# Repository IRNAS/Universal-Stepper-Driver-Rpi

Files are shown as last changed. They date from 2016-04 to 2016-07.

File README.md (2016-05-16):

# Universal Stepper Driver RPi

Here you can find documentation for Universal stepper driver in shape of Raspberry Pi Hat. It supports all signals for Bipolar stepper motors thrue RPi header and have Unipolar stepper connectors and drivers. This driver is GRBL comatibile.

board_diagram
#### Features
- switching power supplay
- USB connector
- current mesurment
- unipolar stepper motor drivers on board
- RPi connector
- encoder connectors
- endswitch connector
- universal serial connector
- 2x LED
- 1x push button

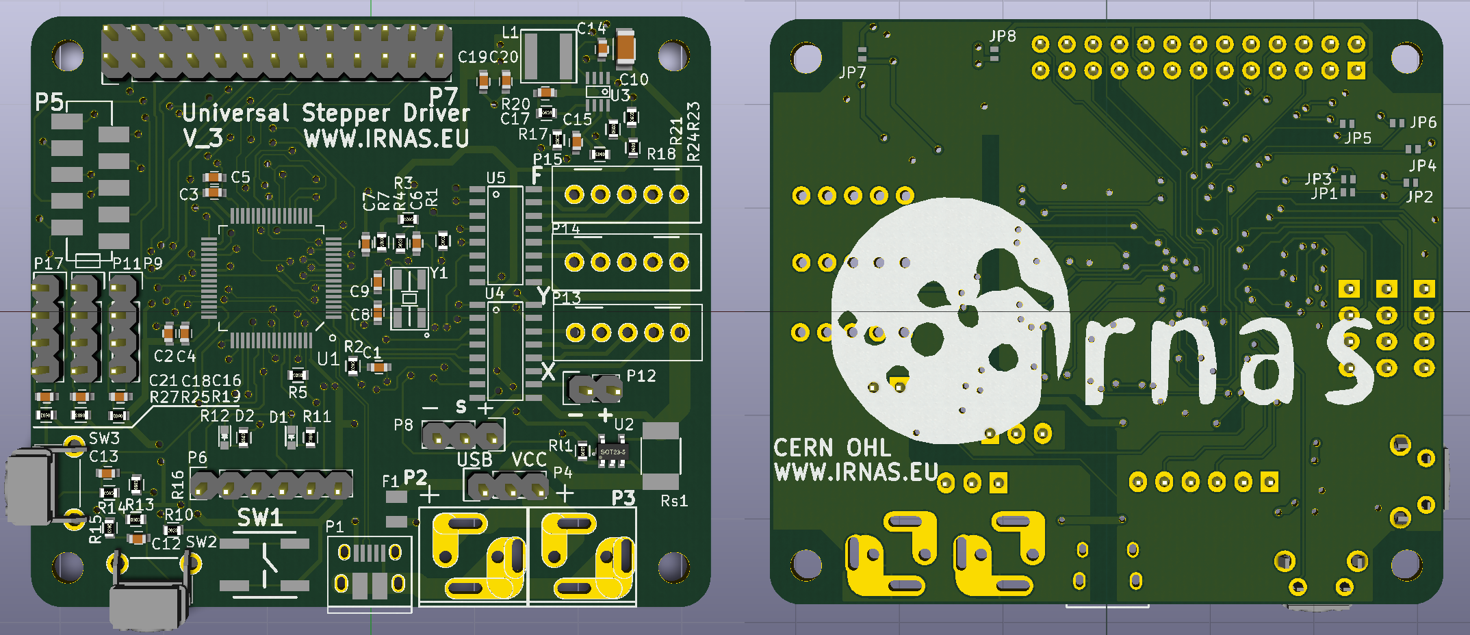
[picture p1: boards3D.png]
board_3D


#### Hardware
Schematics and PCB are designed with open source EDA tool KiCad, all nesesery design files are in this repository.

#### Software
Firmware and all the nessery documentation for Universal Stepper Driver RPi can be found in this [repository](https://github.com/IRNAS/grbl_stm32).

This is currently in testing phase.

#### Known Isues
- Universal serial connector footprint is not good, need to be changed

---

#### License

All our projects are as usefully open-source as possible.

Hardware including documentation is licensed under [CERN OHL v.1.2. license](http://www.ohwr.org/licenses/cern-ohl/v1.2)

Firmware and software originating from the project is licensed under [GNU GENERAL PUBLIC LICENSE v3](http://www.gnu.org/licenses/gpl-3.0.en.html).

Open data generated by our projects is licensed under [CC0](https://creativecommons.org/publicdomain/zero/1.0/legalcode).

All our websites and additional documentation are licensed under [Creative Commons Attribution-ShareAlike 4 .0 Unported License] (https://creativecommons.org/licenses/by-sa/4.0/legalcode).

What this means is that you can use hardware, firmware, software and documentation without paying a royalty and knowing that you'll be able to use your version forever. You are also free to make changes but if you share these changes then you have to do so on the same conditions that you enjoy.

Koruza, GoodEnoughCNC and IRNAS are all names and marks of Institut IRNAS Rače. 
You may use these names and terms only to attribute the appropriate entity as required by the Open Licences referred to above. You may not use them in any other way and in particular you may not use them to imply endorsement or authorization of any hardware that you design, make or sell.

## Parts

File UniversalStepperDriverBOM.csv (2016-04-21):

Id | Designator | Package | Quantity | Designation | Supplier and ref
1 | REF**,REF**,REF**,REF** | MountingHole_3mm | 4 | MountingHole_3mm
2 | C1,C2,C3,C4,C5,C6,C7,C12,C13,C14,C15,C16,C17,C18,C21 | C_0603 | 15 | 100nF
3 | C8,C9 | C_0603 | 2 | 20pF
4 | C10 | C_0603 | 1 | 10uF
5 | C19,C20 | C_0603 | 2 | 22pF
6 | D1 | LED_0603 | 1 | LED_RED
7 | D2 | LED_0603 | 1 | LED_GREEN
8 | F1 | Fuse_SMD1206_Reflow | 1 | F_Small
9 | JP1,JP2,JP3,JP4,JP5,JP6,JP7,JP8 | bridgeJumper | 8 | Jumper_NC_Small
10 | L1 | Inductor SMD XAL50 | 1 | 10uH
11 | P1 | USB_Micro-B_10103594-0001LF | 1 | USB_OTG
12 | P2,P3 | terminal_block_dc_jack_5mm_wide | 2 | CONN_01X02
13 | P4,P8 | Pin_Header_Straight_1x03 | 2 | CONN_01X03
14 | P5 | micromatch | 1 | Universal_Serial_Connector
15 | P6 | Pin_Header_Straight_1x06 | 1 | CONN_01X06
16 | P7 | Pin_Header_Straight_2x13 | 1 | RPI_header
17 | P9,P11,P17 | Pin_Header_Straight_1x04 | 3 | CONN_01X04
18 | P12 | Pin_Header_Straight_1x02 | 1 | CONN_01X02
19 | P13,P14,P15 | 28BYJ-48 | 3 | CONN_28BYJ-48
20 | R1,R2,R3,R4 | R_0603 | 4 | 0R
21 | R5,R10,R19,R25,R27 | R_0603 | 5 | 10k
22 | R7 | R_0603 | 1 | 100k
23 | R11,R12 | R_0603 | 2 | 1k
24 | R13,R14 | R_0603 | 2 | 4k7
25 | R15,R16 | R_0603 | 2 | 100R
26 | R17 | R_0603 | 1 | 1M
27 | R18 | R_0603 | 1 | 100K
28 | R20 | R_0603 | 1 | 20R
29 | R21 | R_0603 | 1 | 51k
30 | R23 | R_0603 | 1 | 13k
31 | R24 | R_0603 | 1 | 41k2
32 | Rl1 | R_0603 | 1 | 16k5
33 | Rs1 | R_1812 | 1 | 0.1R
34 | U1 | QFP_64 | 1 | STM32F411RE
35 | U2 | SOT-23-5 | 1 | INA169
36 | U3 | TSOT32-8 | 1 | MPQ4420
37 | U4,U5 | R-PDSO-G16 | 2 | ULN2003V
38 | Y1 | SPK5032 | 1 | CRYSTAL_SMD_16MHz
39 | SW2,SW3 | SW_Tactile_SPST_Angled | 2 | SW_PUSH
40 | SW1 | KSEK43J_LFS_TACTILE_SWITCH | 1 | SW_PUSH
41 | G*** | LOGO_irnas1 | 1 | LOGO

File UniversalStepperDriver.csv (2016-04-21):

Reference, | Value, | Footprint, | Datasheet
P1,USB_OTG,Connect:USB_Micro-B_10103594-0001LF,http://www.farnell.com/datasheets/1469075.pdf
F1,F_Small,Fuse_Holders_and_Fuses:Fuse_SMD1206_Reflow,http://www.tme.eu/en/Document/92540abe48b0088862e73e73da7a3377/typ_USI_1206.pdf
P2,CONN_01X02,.pretty:terminal_block_dc_jack_5mm_wide,
P3,CONN_01X02,.pretty:terminal_block_dc_jack_5mm_wide,
P4,CONN_01X03,Pin_Headers:Pin_Header_Straight_1x03,
U2,INA169,TO_SOT_Packages_SMD:SOT-23-5,http://www.ti.com/lit/ds/symlink/ina169.pdf
Rl1,16k5,Resistors_SMD:R_0603,
Rs1,0.1R,Resistors_SMD:R_1812,
U3,MPQ4420,.pretty:TSOT32-8,
C10,10uF,Capacitors_SMD:C_0603,
C14,100nF,Capacitors_SMD:C_0603,
R17,1M,Resistors_SMD:R_0603,
R18,100K,Resistors_SMD:R_0603,
C15,100nF,Capacitors_SMD:C_0603,
R20,20R,Resistors_SMD:R_0603,
C17,100nF,Capacitors_SMD:C_0603,
L1,10uH,.pretty:Inductor | SMD | XAL50,
C19,22pF,Capacitors_SMD:C_0603,
C20,22pF,Capacitors_SMD:C_0603,
R21,51k,Resistors_SMD:R_0603,
R24,41k2,Resistors_SMD:R_0603,
R23,13k,Resistors_SMD:R_0603,
P13,CONN_28BYJ-48,.pretty:28BYJ-48,
P14,CONN_28BYJ-48,.pretty:28BYJ-48,
P15,CONN_28BYJ-48,.pretty:28BYJ-48,
P9,CONN_01X04,Pin_Headers:Pin_Header_Straight_1x04,
P11,CONN_01X04,Pin_Headers:Pin_Header_Straight_1x04,
P17,CONN_01X04,Pin_Headers:Pin_Header_Straight_1x04,
R19,10k,Resistors_SMD:R_0603,
R25,10k,Resistors_SMD:R_0603,
R27,10k,Resistors_SMD:R_0603,
C16,100nF,Capacitors_SMD:C_0603,
C18,100nF,Capacitors_SMD:C_0603,
C21,100nF,Capacitors_SMD:C_0603,
SW2,SW_PUSH,Buttons_Switches_ThroughHole:SW_Tactile_SPST_Angled,www.ck-http://www.farnell.com/datasheets/921681.pdf
SW3,SW_PUSH,Buttons_Switches_ThroughHole:SW_Tactile_SPST_Angled,http://www.farnell.com/datasheets/921681.pdf
R15,100R,Resistors_SMD:R_0603,
R16,100R,Resistors_SMD:R_0603,
C12,100nF,Capacitors_SMD:C_0603,
C13,100nF,Capacitors_SMD:C_0603,
R14,4k7,Resistors_SMD:R_0603,
R13,4k7,Resistors_SMD:R_0603,
P5,Universal_Serial_Connector,.pretty:micromatch,
JP1,Jumper_NC_Small,.pretty:bridgeJumper,
C1,100nF,Capacitors_SMD:C_0603,
C2,100nF,Capacitors_SMD:C_0603,
C3,100nF,Capacitors_SMD:C_0603,
C4,100nF,Capacitors_SMD:C_0603,
C5,100nF,Capacitors_SMD:C_0603,
R3,0R,Resistors_SMD:R_0603,
R4,0R,Resistors_SMD:R_0603,
C6,100nF,Capacitors_SMD:C_0603,
U1,STM32F411RE,.pretty:QFP_64,http://www2.st.com/content/ccc/resource/technical/document/datasheet/b3/a5/46/3b/b4/e5/4c/85/DM00115249.pdf/files/DM00115249.pdf/jcr:content/translations/en.D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
R2,0R,Resistors_SMD:R_0603,
R1,0R,Resistors_SMD:R_0603,
R5,10k,Resistors_SMD:R_0603,
R7,100k,Resistors_SMD:R_0603,
C7,100nF,Capacitors_SMD:C_0603,
R12,1k,Resistors_SMD:R_0603,
D2,LED_GREEN,LEDs:LED_0603,
D1,LED_RED,LEDs:LED_0603,
P6,CONN_01X06,Pin_Headers:Pin_Header_Straight_1x06,
C8,20pF,Capacitors_SMD:C_0603,
C9,20pF,Capacitors_SMD:C_0603,
Y1,CRYSTAL_SMD_16MHz,.pretty:SPK5032,https://www.sparkfun.com/datasheets/Components/SPK-5032-16MHZ.pdf
P12,CONN_01X02,Pin_Headers:Pin_Header_Straight_1x02,
P8,CONN_01X03,Pin_Headers:Pin_Header_Straight_1x03,
R10,10k,Resistors_SMD:R_0603,
R11,1k,Resistors_SMD:R_0603,
SW1,SW_PUSH,KSEK43J_LFS_TACTILE_SWITCH:KSEK43J_LFS_TACTILE_SWITCH,http://www.farnell.com/datasheets/1839884.pdf
U4,ULN2003V,.pretty:R-PDSO-G16,
U5,ULN2003V,.pretty:R-PDSO-G16,
JP2,Jumper_NC_Small,.pretty:bridgeJumper,
JP3,Jumper_NC_Small,.pretty:bridgeJumper,
JP4,Jumper_NC_Small,.pretty:bridgeJumper,
JP5,Jumper_NC_Small,.pretty:bridgeJumper,
JP6,Jumper_NC_Small,.pretty:bridgeJumper,
P7,RPI_header,Pin_Headers:Pin_Header_Straight_2x13,http://pi4j.com/images/p1header-large.png
JP7,Jumper_NC_Small,.pretty:bridgeJumper,
JP8,Jumper_NC_Small,.pretty:bridgeJumper,

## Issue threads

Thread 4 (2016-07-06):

VDDA pin (pin #13) must allways be connected to +3V3.

MatejGomboc, 2016-07-06:
VDDA pin (pin #13) must allways be connected to +3V3, otherwise MCU cannot be programmed.

VojislavM, 2016-07-18:
R3 and R1 resistors (0 Ohm) must be soldered.

Closed 2016-07-18.

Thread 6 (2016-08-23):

Pin order on SWD debug interface is reversed.

MatejGomboc, 2016-08-23:
Pin order on SWD debug interface is reversed. It should be:

1. - 3V3
2. - TCK
3. - GND
4. - TMS
5. - NRST
6. - SWO

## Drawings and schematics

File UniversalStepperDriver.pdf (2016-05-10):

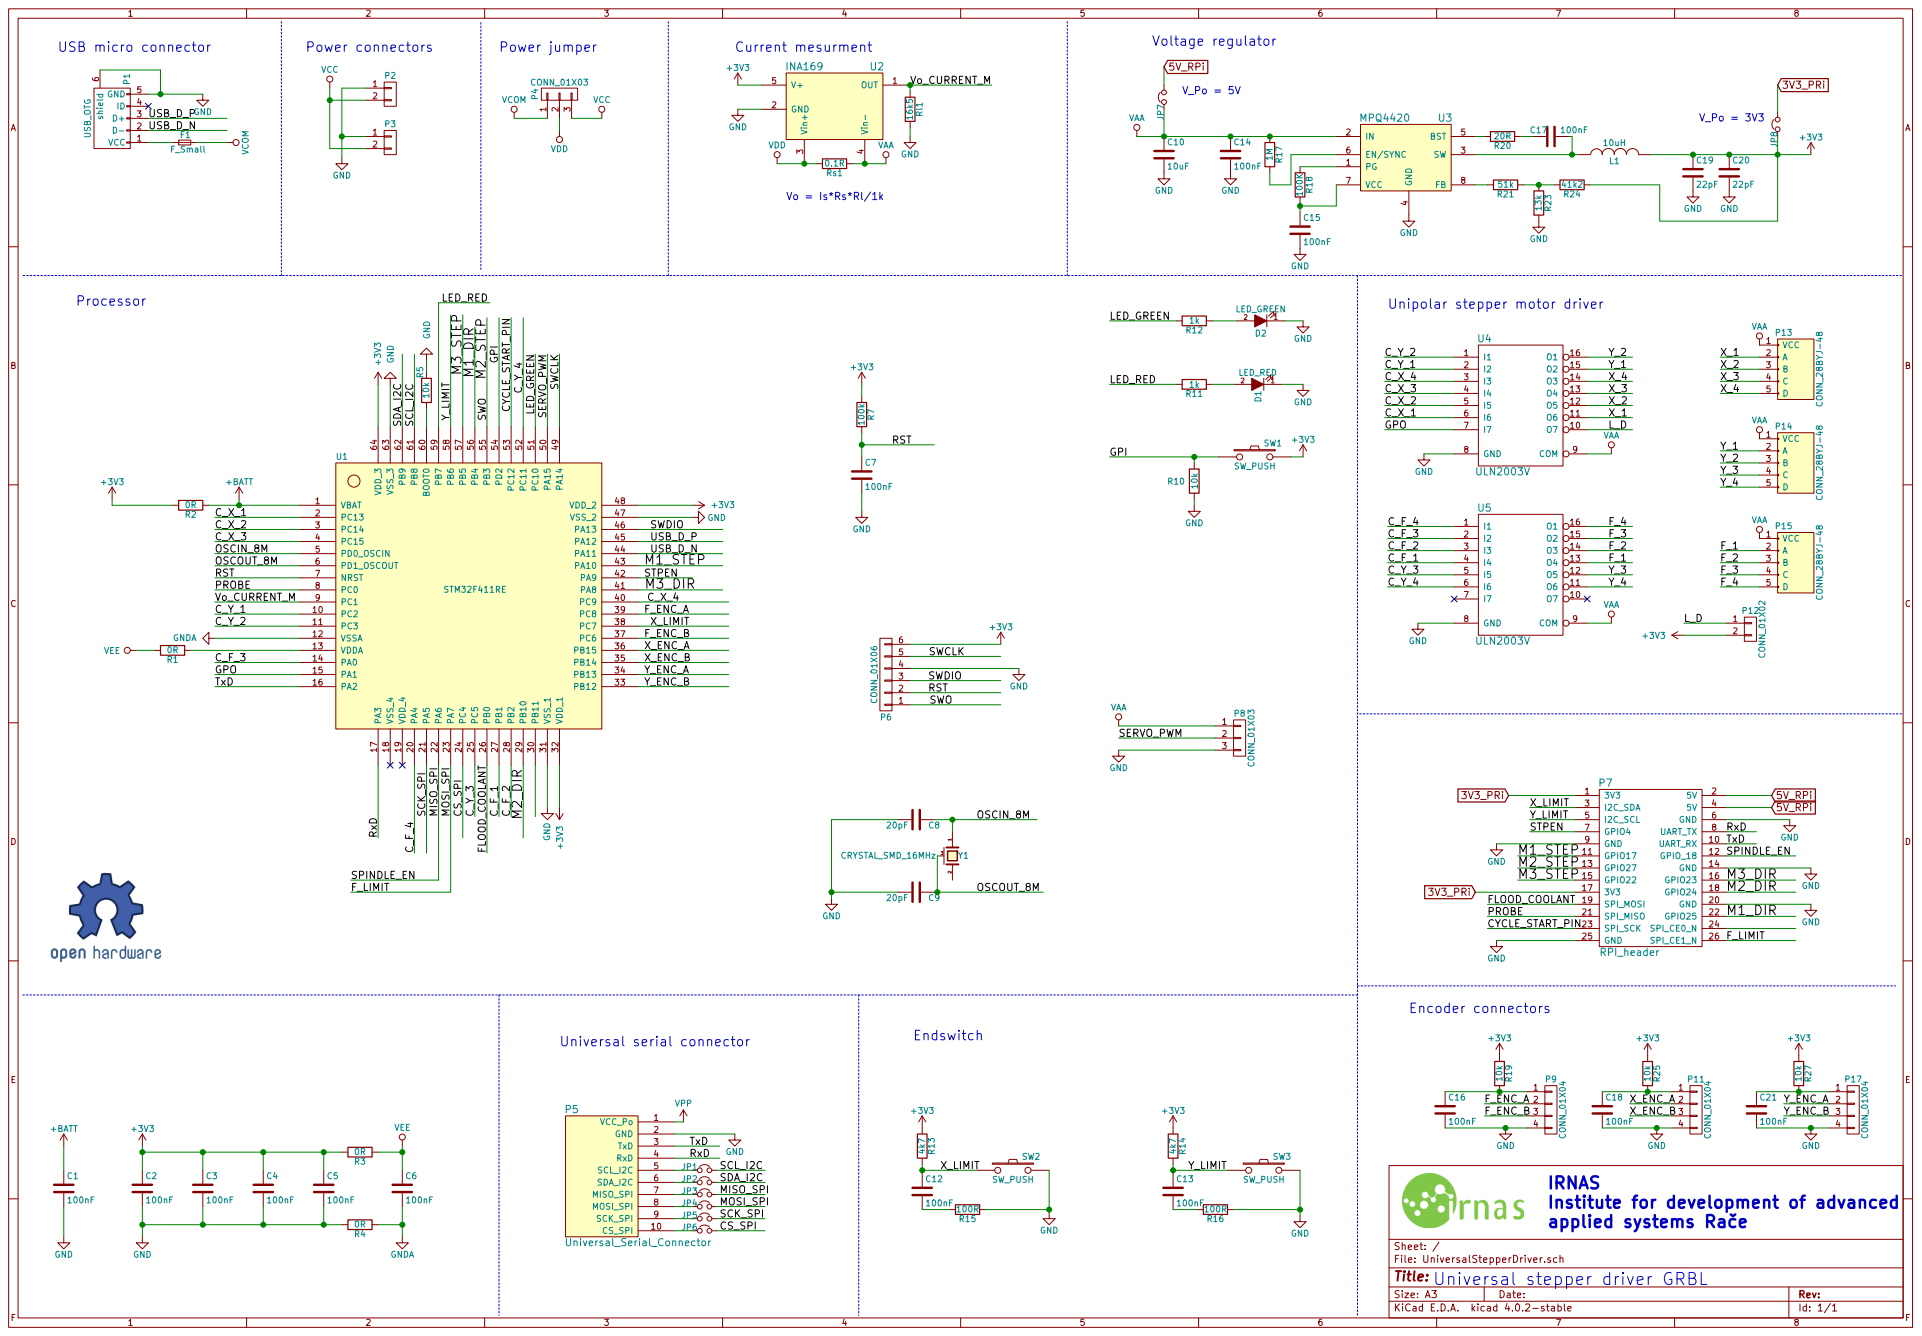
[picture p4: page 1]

4 BST 5 EN/SYNC 6 VCC 7 FB 8 MPQ4420 U3 C10

Unipolar stepper motor driver

F_ENC_A
X_LIMIT

GND Universal serial connector

Institute for development of advanced
applied systems Rae

File: UniversalStepperDriver.sch Sheet: /
Universal stepper driver GRBL

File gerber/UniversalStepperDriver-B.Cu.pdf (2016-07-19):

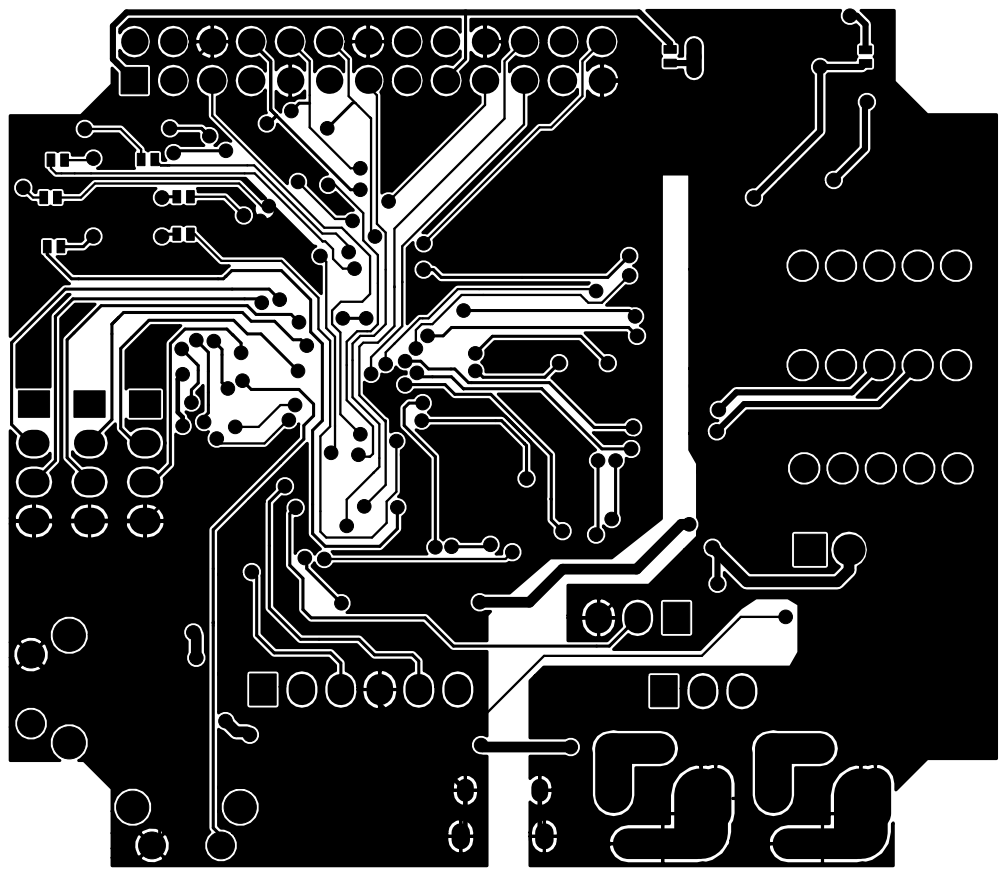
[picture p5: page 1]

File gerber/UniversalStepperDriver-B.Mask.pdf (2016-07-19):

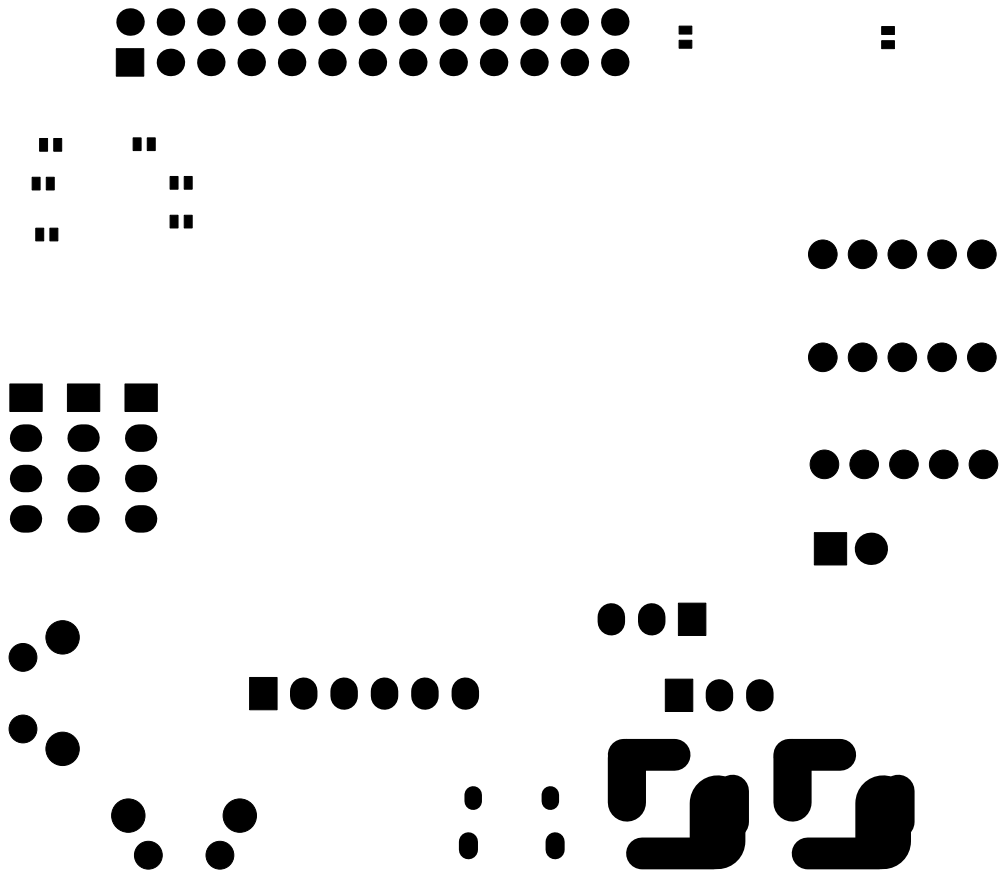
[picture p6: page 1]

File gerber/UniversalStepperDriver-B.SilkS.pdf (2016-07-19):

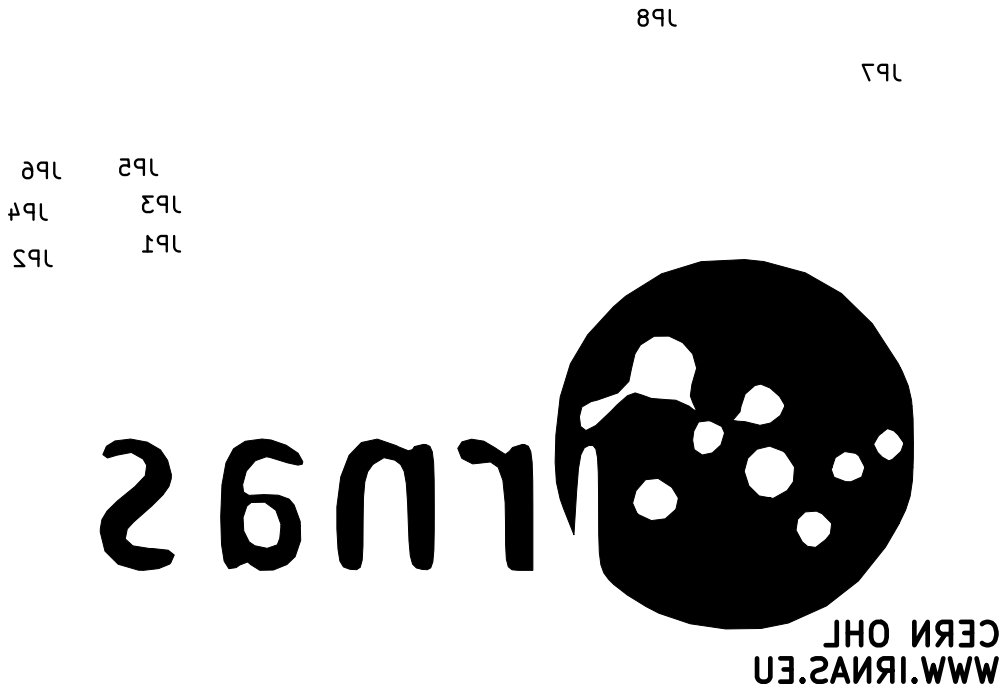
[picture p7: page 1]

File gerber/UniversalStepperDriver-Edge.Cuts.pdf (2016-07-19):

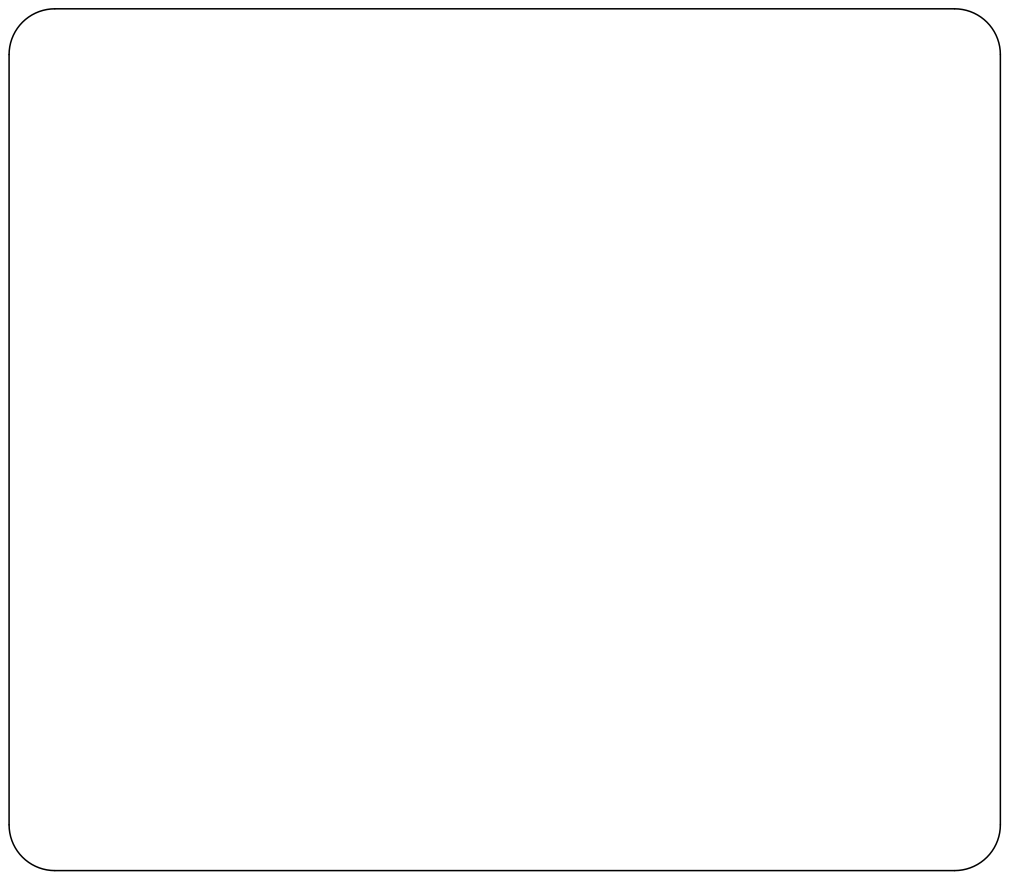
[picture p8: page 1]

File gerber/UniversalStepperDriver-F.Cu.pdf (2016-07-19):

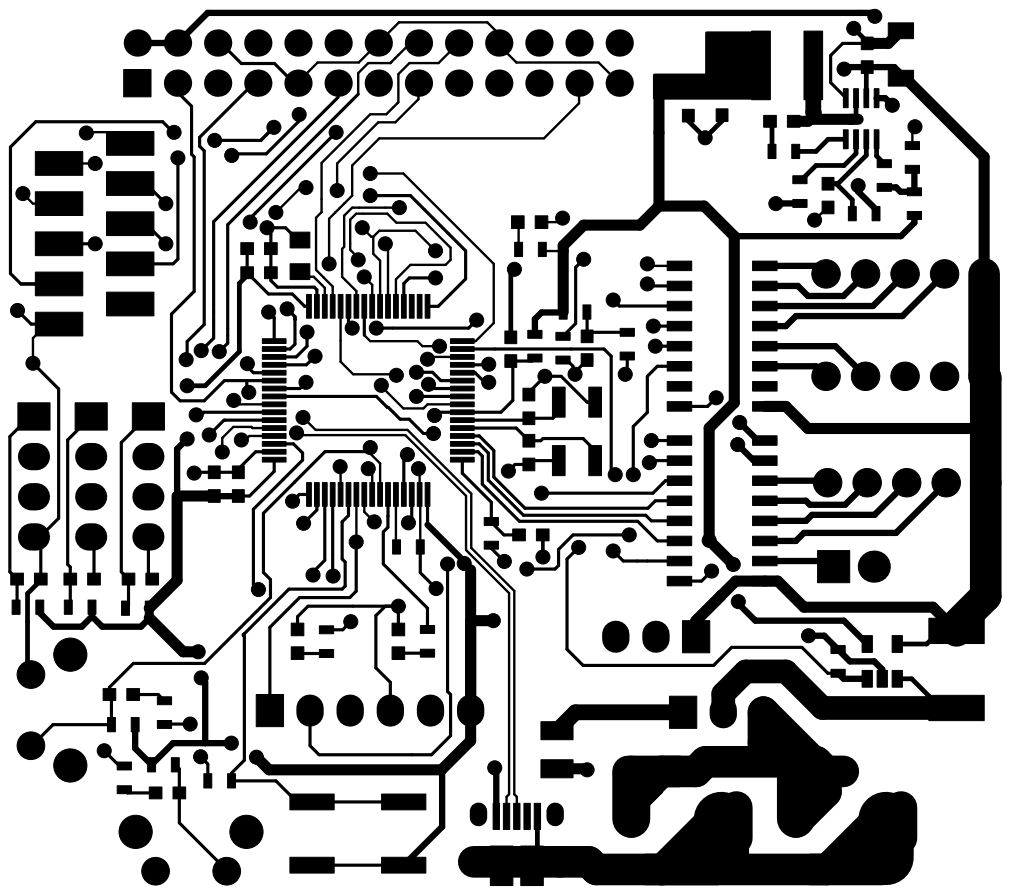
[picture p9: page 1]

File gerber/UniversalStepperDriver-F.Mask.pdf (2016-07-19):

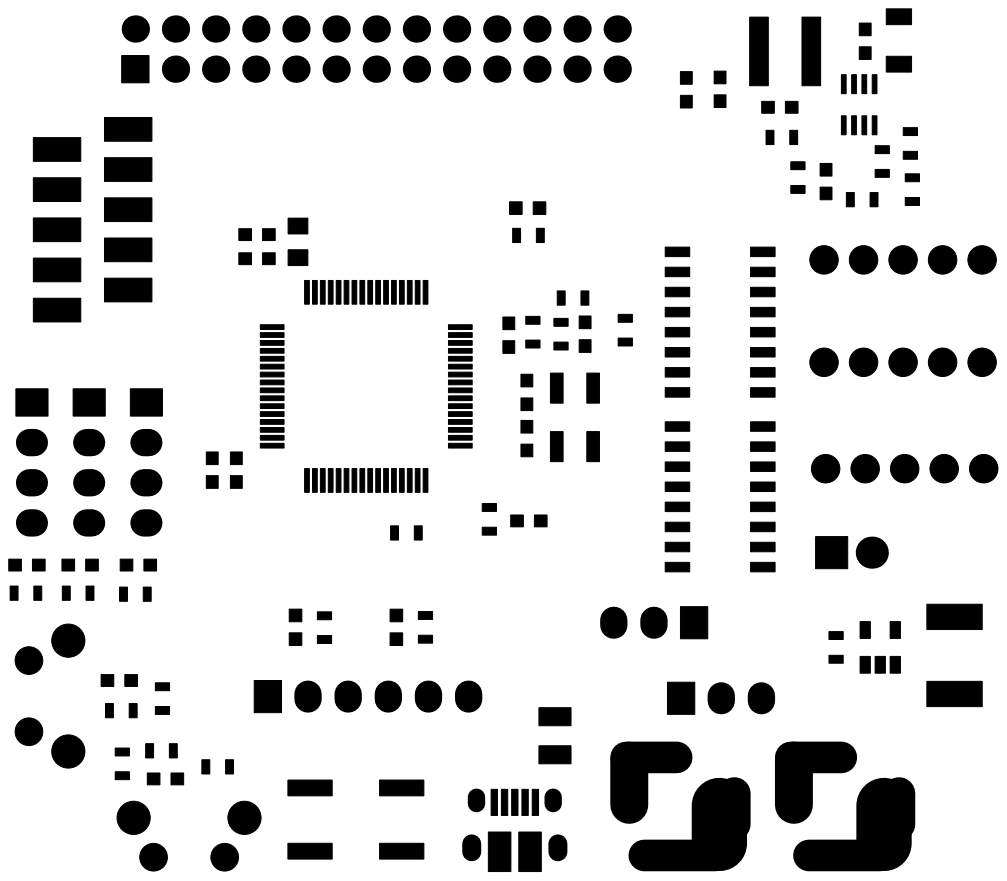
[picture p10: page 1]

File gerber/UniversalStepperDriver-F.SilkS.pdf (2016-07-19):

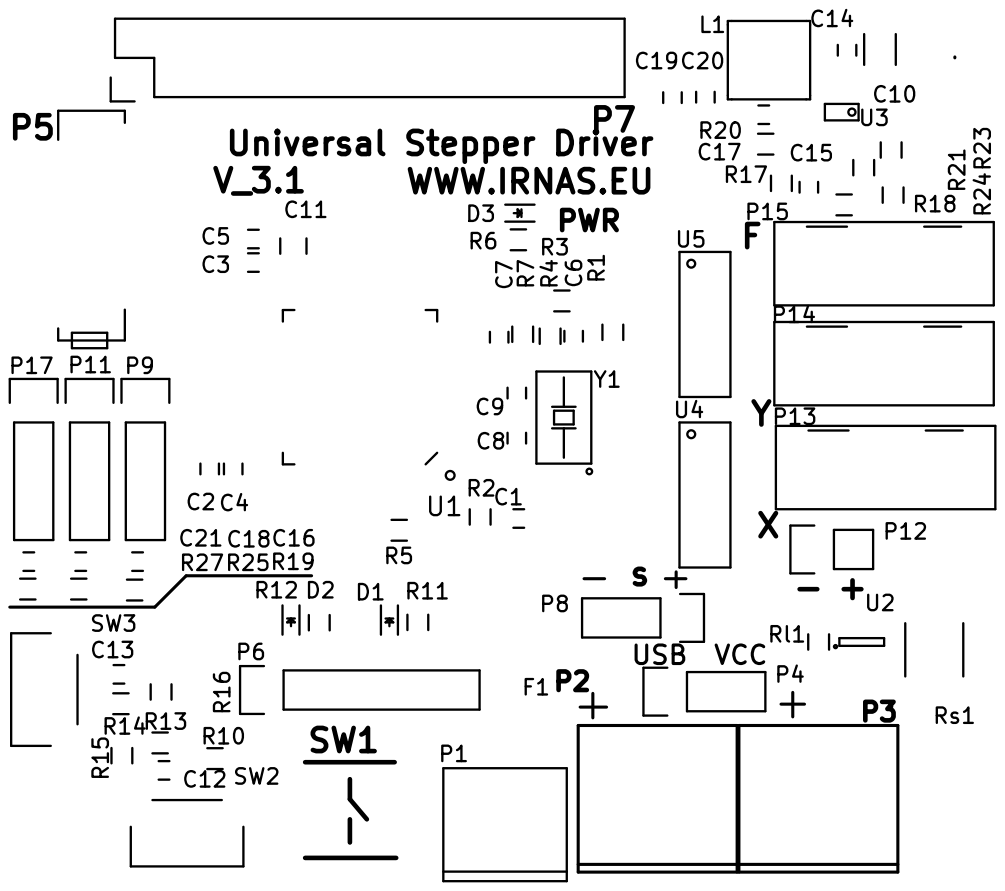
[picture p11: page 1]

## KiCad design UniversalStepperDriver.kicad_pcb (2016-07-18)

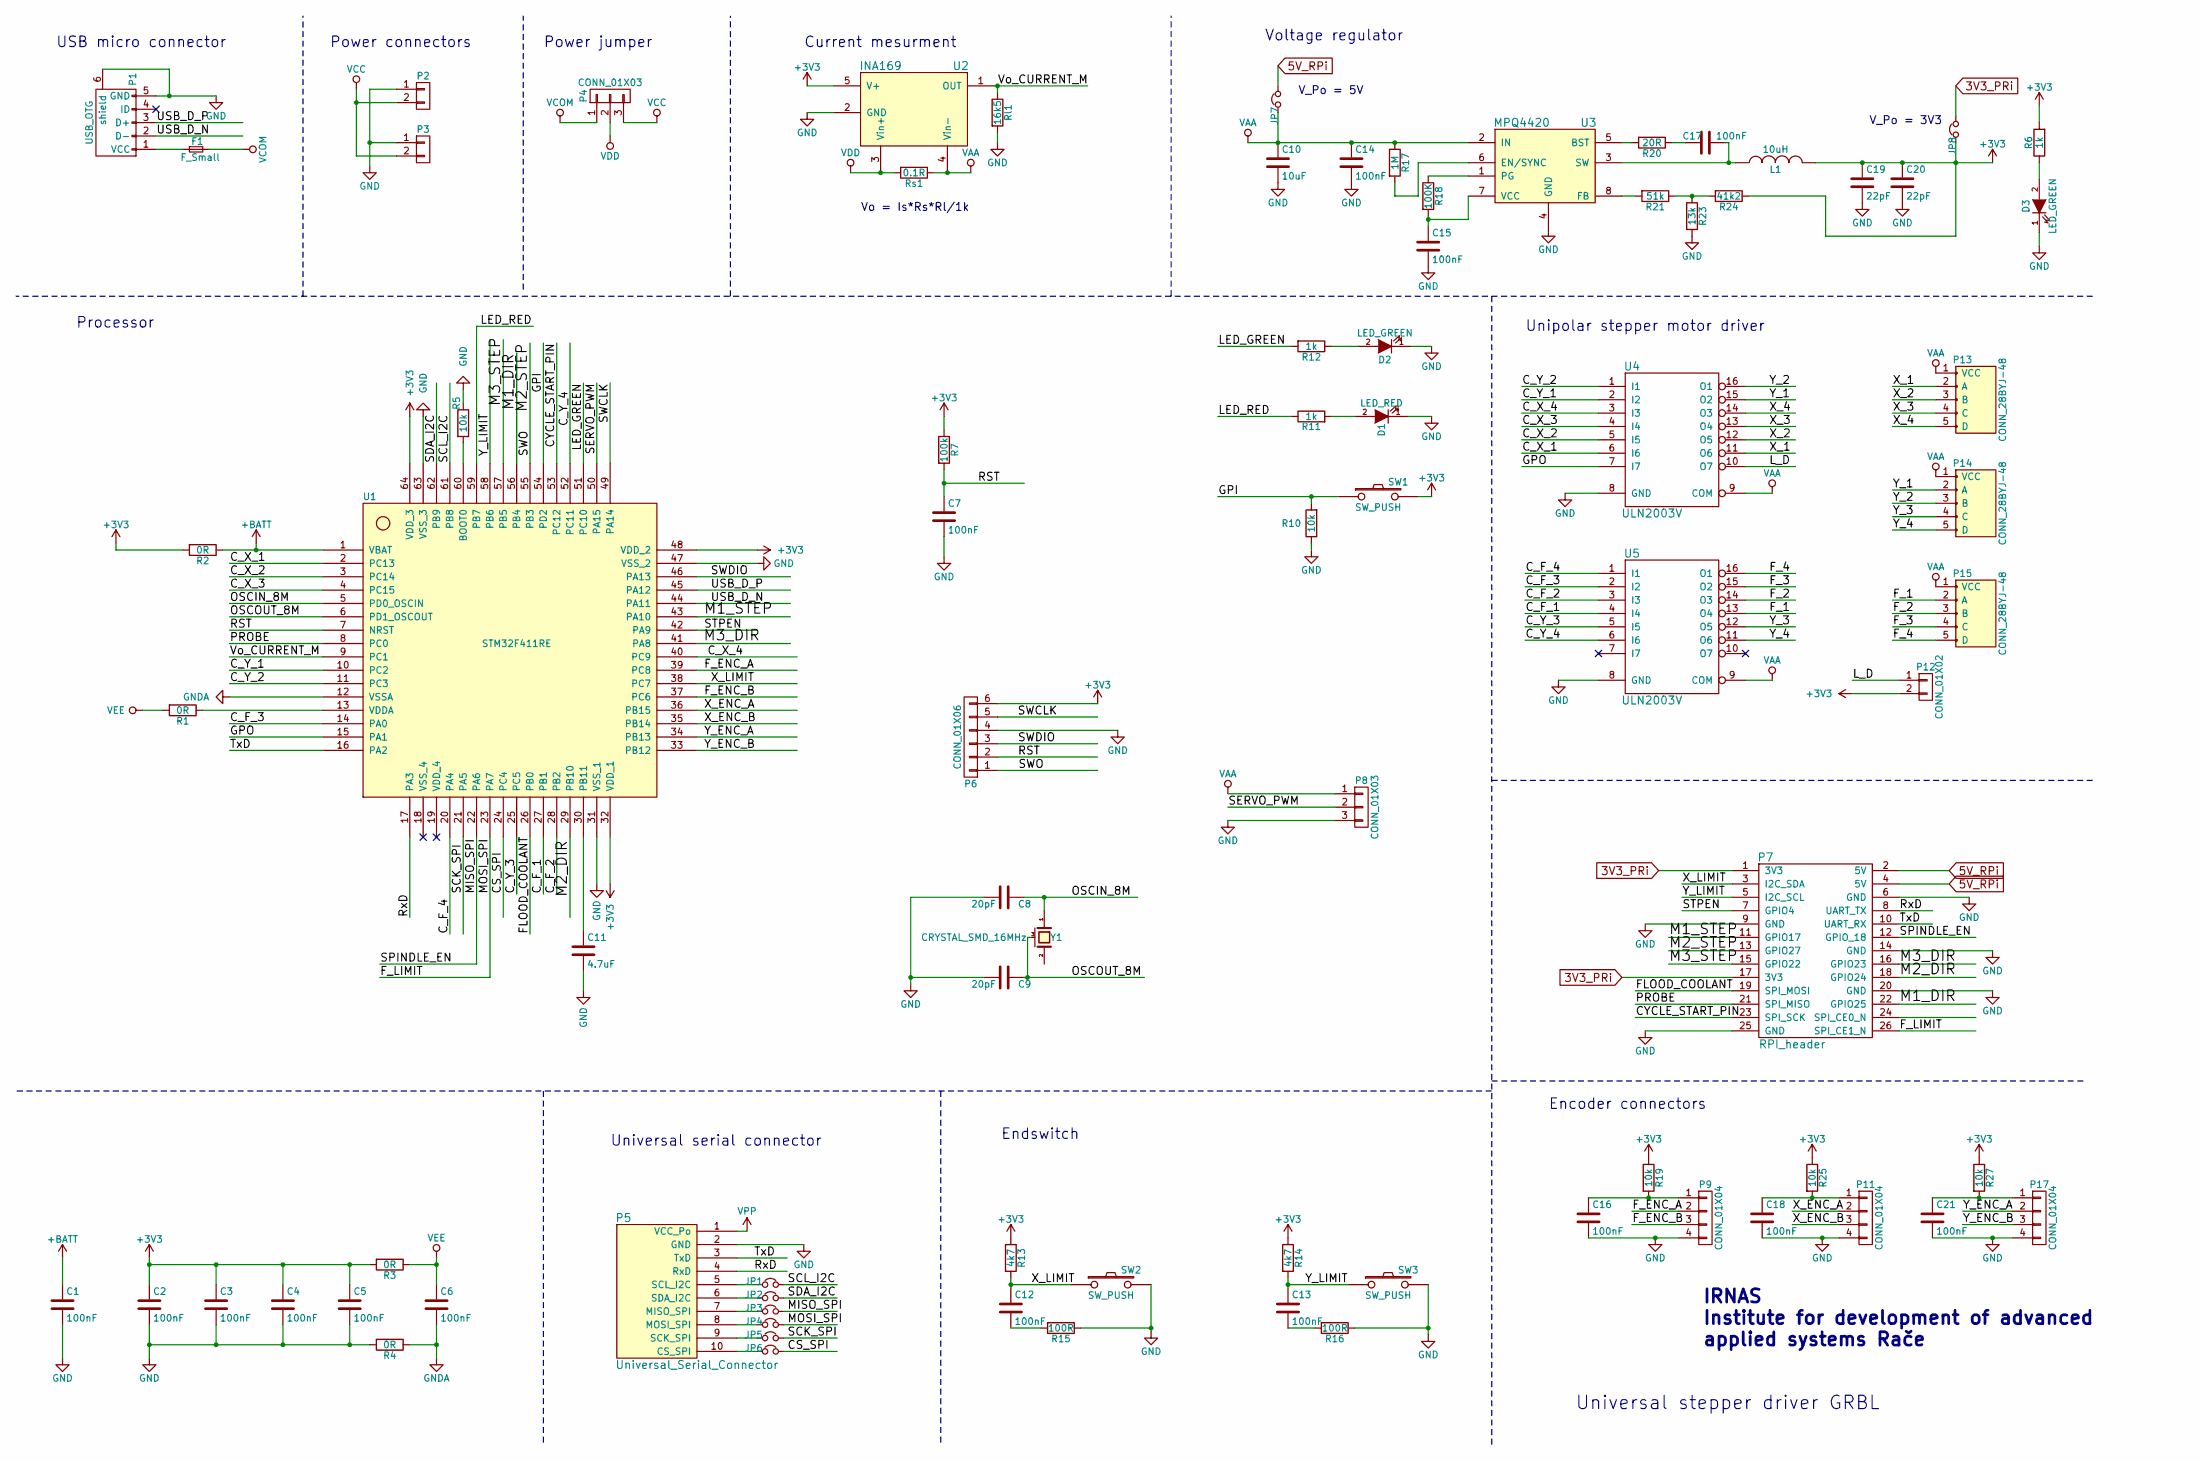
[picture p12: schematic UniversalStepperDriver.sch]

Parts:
C1, C2, C3, C4, C5, C6, C7, C12, C13, C14, C15, C16, C17, C18, C21: 100nF; C_0603
C8, C9: 20pF; C_0603
C10: 10uF; C_0603
C11: 4.7uF; C_0805
C19, C20: 22pF; C_0603
D1: LED_RED; LED_0603
D2, D3: LED_GREEN; LED_0603
F1: F_Small; Fuse_SMD1206_Reflow
JP1, JP2, JP3, JP4, JP5, JP6, JP7, JP8: Jumper_NC_Small; bridgeJumper
L1: 10uH; Inductor SMD XAL50
P1: USB_OTG; USB_Micro-B_10103594-0001LF
P2, P3: CONN_01X02; terminal_block_dc_jack_5mm_wide
P4, P8: CONN_01X03; Pin_Header_Straight_1x03
P5: Universal_Serial_Connector; micromatch
P6: CONN_01X06; Pin_Header_Straight_1x06
P7: RPI_header; Pin_Header_Straight_2x13
P9, P11, P17: CONN_01X04; Pin_Header_Straight_1x04
P12: CONN_01X02; Pin_Header_Straight_1x02
P13, P14, P15: CONN_28BYJ-48; 28BYJ-48
R1, R2, R3, R4: 0R; R_0603
R5, R10, R19, R25, R27: 10k; R_0603
R6, R11, R12: 1k; R_0603
R7: 100k; R_0603
R13, R14: 4k7; R_0603
R15, R16: 100R; R_0603
R17: 1M; R_0603
R18: 100K; R_0603
R20: 20R; R_0603
R21: 51k; R_0603
R23: 13k; R_0603
R24: 41k2; R_0603
Rl1: 16k5; R_0603
Rs1: 0.1R; R_1812
SW1: SW_PUSH; KSEK43J_LFS_TACTILE_SWITCH
SW2, SW3: SW_PUSH; SW_Tactile_SPST_Angled
U1: STM32F411RE; QFP_64
U2: INA169; SOT-23-5
U3: MPQ4420; TSOT32-8
U4, U5: ULN2003V; R-PDSO-G16
Y1: CRYSTAL_SMD_16MHz; SPK5032

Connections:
3V3_PRi: JP8.2, P7.1 (3V3), P7.17 (3V3)
5V_RPi: JP7.2, P7.2 (5V), P7.4 (5V)
+3V3: C2.1, C3.1, C4.1, C5.1, C19.1, C20.1, JP8.1, L1.2, P6.6, P12.2, R2.2, R3.2, R6.2, R7.1, R13.1, R14.1, R19.1, R24.1, R25.1, R27.1, SW1.2, U1.32 (VDD_1), U1.48 (VDD_2), U1.64 (VDD_3), U2.5 (V+)
+BATT: C1.1, R2.1, U1.1 (VBAT)
/CS_SPI: JP6.2, U1.24 (PC4)
/CYCLE_START_PIN: P7.23 (SPI_SCK), U1.53 (PC12)
/C_F_1: U1.27 (PB1), U5.4 (I4)
/C_F_2: U1.28 (PB2), U5.3 (I3)
/C_F_3: U1.14 (PA0), U5.2 (I2)
/C_F_4: U1.20 (PA4), U5.1 (I1)
/C_X_1: U1.2 (PC13), U4.6 (I6)
/C_X_2: U1.3 (PC14), U4.5 (I5)
/C_X_3: U1.4 (PC15), U4.4 (I4)
/C_X_4: U1.40 (PC9), U4.3 (I3)
/C_Y_1: U1.10 (PC2), U4.2 (I2)
/C_Y_2: U1.11 (PC3), U4.1 (I1)
/C_Y_3: U1.25 (PC5), U5.5 (I5)
/C_Y_4: U1.52 (PC11), U5.6 (I6)
/FLOOD_COOLANT: P7.19 (SPI_MOSI), U1.26 (PB0)
/F_1: P15.2 (A), U5.13 (O4)
/F_2: P15.3 (B), U5.14 (O3)
/F_3: P15.4 (C), U5.15 (O2)
/F_4: P15.5 (D), U5.16 (O1)
/F_ENC_A: P9.2, U1.39 (PC8)
/F_ENC_B: P9.3, U1.37 (PC6)
/F_LIMIT: JP4.2, P7.26 (SPI_CE1_N), U1.23 (PA7)
/GPI: R10.2, SW1.1, U1.54 (PD2)
/GPO: U1.15 (PA1), U4.7 (I7)
/LED_GREEN: R12.2, U1.51 (PC10)
/LED_RED: R11.1, U1.59 (PB7)
/L_D: P12.1, U4.10 (O7)
/M1_DIR: P7.22 (GPIO25), U1.56 (PB4)
/M1_STEP: P7.11 (GPIO17), U1.43 (PA10)
/M2_DIR: P7.18 (GPIO24), U1.29 (PB10)
/M2_STEP: P6.1, P7.13 (GPIO27), U1.55 (PB3)
/M3_DIR: P7.16 (GPIO23), U1.41 (PA8)
/M3_STEP: P7.15 (GPIO22), U1.57 (PB5)
/MISO_SPI: JP3.2, P7.12 (GPIO_18), U1.22 (PA6)
/OSCIN_8M: C8.1, U1.5 (PD0_OSCIN), Y1.1
/OSCOUT_8M: C9.1, U1.6 (PD1_OSCOUT), Y1.3 (case)
/PROBE: P7.21 (SPI_MISO), U1.8 (PC0)
/RST: C7.1, P6.2, R7.2, U1.7 (NRST)
/RxD: P5.4 (RxD), P7.8 (UART_TX), U1.17 (PA3)
/SCK_SPI: JP5.2, U1.21 (PA5)
/SCL_I2C: JP1.2, U1.61 (PB8)
/SDA_I2C: JP2.2, U1.62 (PB9)
/SERVO_PWM: P8.2, U1.50 (PA15)
/STPEN: P7.7 (GPIO4), U1.42 (PA9)
/SWCLK: P6.5, U1.49 (PA14)
/SWDIO: P6.3, U1.46 (PA13)
/TxD: P5.3 (TxD), P7.10 (UART_RX), U1.16 (PA2)
/USB_D_N: P1.2 (D-), U1.44 (PA11)
/USB_D_P: P1.3 (D+), U1.45 (PA12)
/Vo_CURRENT_M: Rl1.1, U1.9 (PC1), U2.1 (OUT)
/X_1: P13.2 (A), U4.11 (O6)
/X_2: P13.3 (B), U4.12 (O5)
/X_3: P13.4 (C), U4.13 (O4)
/X_4: P13.5 (D), U4.14 (O3)
/X_ENC_A: P11.2, U1.36 (PB15)
/X_ENC_B: P11.3, U1.35 (PB14)
/X_LIMIT: C12.1, P7.3 (I2C_SDA), R13.2, SW2.1, U1.38 (PC7)
/Y_1: P14.2 (A), U4.15 (O2)
/Y_2: P14.3 (B), U4.16 (O1)
/Y_3: P14.4 (C), U5.12 (O5)
/Y_4: P14.5 (D), U5.11 (O6)
/Y_ENC_A: P17.2, U1.34 (PB13)
/Y_ENC_B: P17.3, U1.33 (PB12)
/Y_LIMIT: C13.1, P7.5 (I2C_SCL), R14.2, SW3.1, U1.58 (PB6)
GND: C1.2, C2.2, C3.2, C4.2, C5.2, C7.2, C8.2, C9.2, C10.2, C11.2, C14.2, C15.2, C16.2, C18.2, C19.2, C20.2, C21.2, D1.1 (K), D2.1 (K), D3.1 (K), P1.5 (GND), P1.6 (shield), P2.1, P3.1, P5.2 (GND), P6.4, P7.6 (GND), P7.9 (GND), P7.14 (GND), P7.20 (GND), P7.25 (GND), P8.3, P9.4, P11.4, P17.4, R4.2, R5.1, R10.1, R15.1, R16.1, R23.2, Rl1.2, SW2.2, SW3.2, U1.31 (VSS_1), U1.47 (VSS_2), U1.63 (VSS_3), U2.2 (GND), U3.4 (GND), U4.8 (GND), U5.8 (GND)
GNDA: C6.2, R4.1, U1.12 (VSSA)
unnamed: C11.1, U1.30 (PB11)
unnamed: C12.2, R15.2
unnamed: C13.2, R16.2
unnamed: C15.1, R18.2, U3.7 (VCC)
unnamed: C16.1, P9.1, R19.2
unnamed: C17.1, L1.1, U3.3 (SW)
unnamed: C17.2, R20.1
unnamed: C18.1, P11.1, R25.2
unnamed: C21.1, P17.1, R27.2
unnamed: D1.2 (A), R11.2
unnamed: D2.2 (A), R12.1
unnamed: D3.2 (A), R6.1
unnamed: F1.1, P1.1 (VCC)
unnamed: JP1.1, P5.5 (SCL_I2C)
unnamed: JP2.1, P5.6 (SDA_I2C)
unnamed: JP3.1, P5.7 (MISO_SPI)
unnamed: JP4.1, P5.8 (MOSI_SPI)
unnamed: JP5.1, P5.9 (SCK_SPI)
unnamed: JP6.1, P5.10 (CS_SPI)
unnamed: R1.1, U1.13 (VDDA)
unnamed: R5.2, U1.60 (BOOT0)
unnamed: R17.2, U3.6 (EN/SYNC)
unnamed: R18.1, U3.1 (PG)
unnamed: R20.2, U3.5 (BST)
unnamed: R21.1, R23.1, R24.2
unnamed: R21.2, U3.8 (FB)
VAA: C10.1, C14.1, JP7.1, P8.1, P13.1 (VCC), P14.1 (VCC), P15.1 (VCC), R17.1, Rs1.1, U2.4 (Vin-), U3.2 (IN), U4.9 (COM), U5.9 (COM)
VCC: P2.2, P3.2, P4.3
VCOM: F1.2, P4.1
VDD: P4.2, Rs1.2, U2.3 (Vin+)
VEE: C6.1, R1.2, R3.1
VPP: P5.1 (VCC_Po)

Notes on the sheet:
Vo = Is*Rs*Rl/1k
V_Po = 5V
V_Po = 3V3
USB micro connector
Power connectors
Power jumper
Current mesurment
Voltage regulator
Unipolar stepper motor driver
Universal serial connector
Encoder connectors
Processor
IRNAS Institute for development of advanced applied systems Rače
Universal stepper driver GRBL
Endswitch

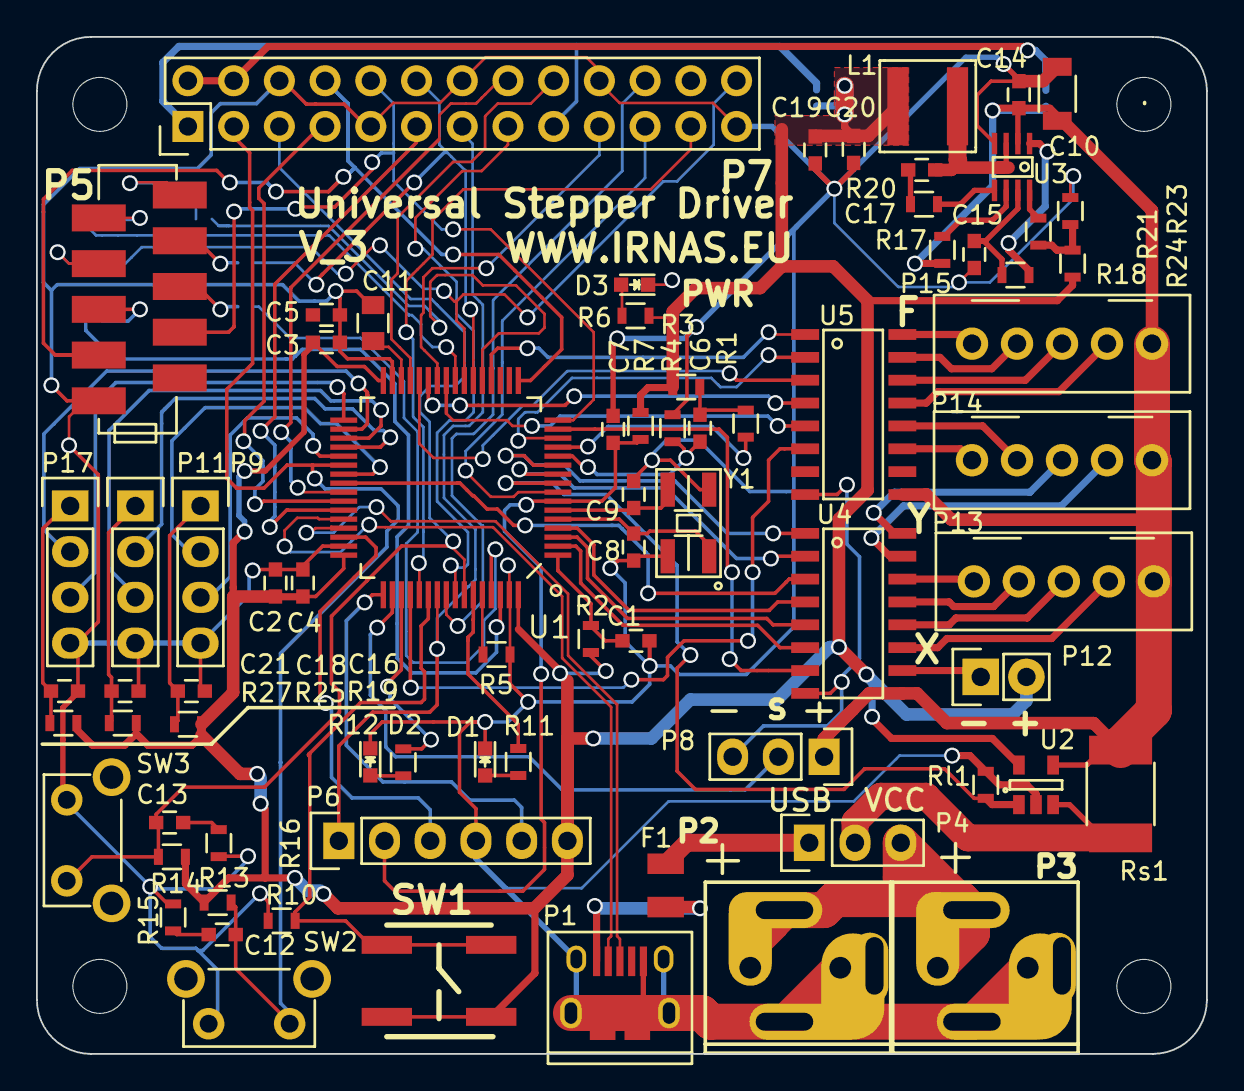
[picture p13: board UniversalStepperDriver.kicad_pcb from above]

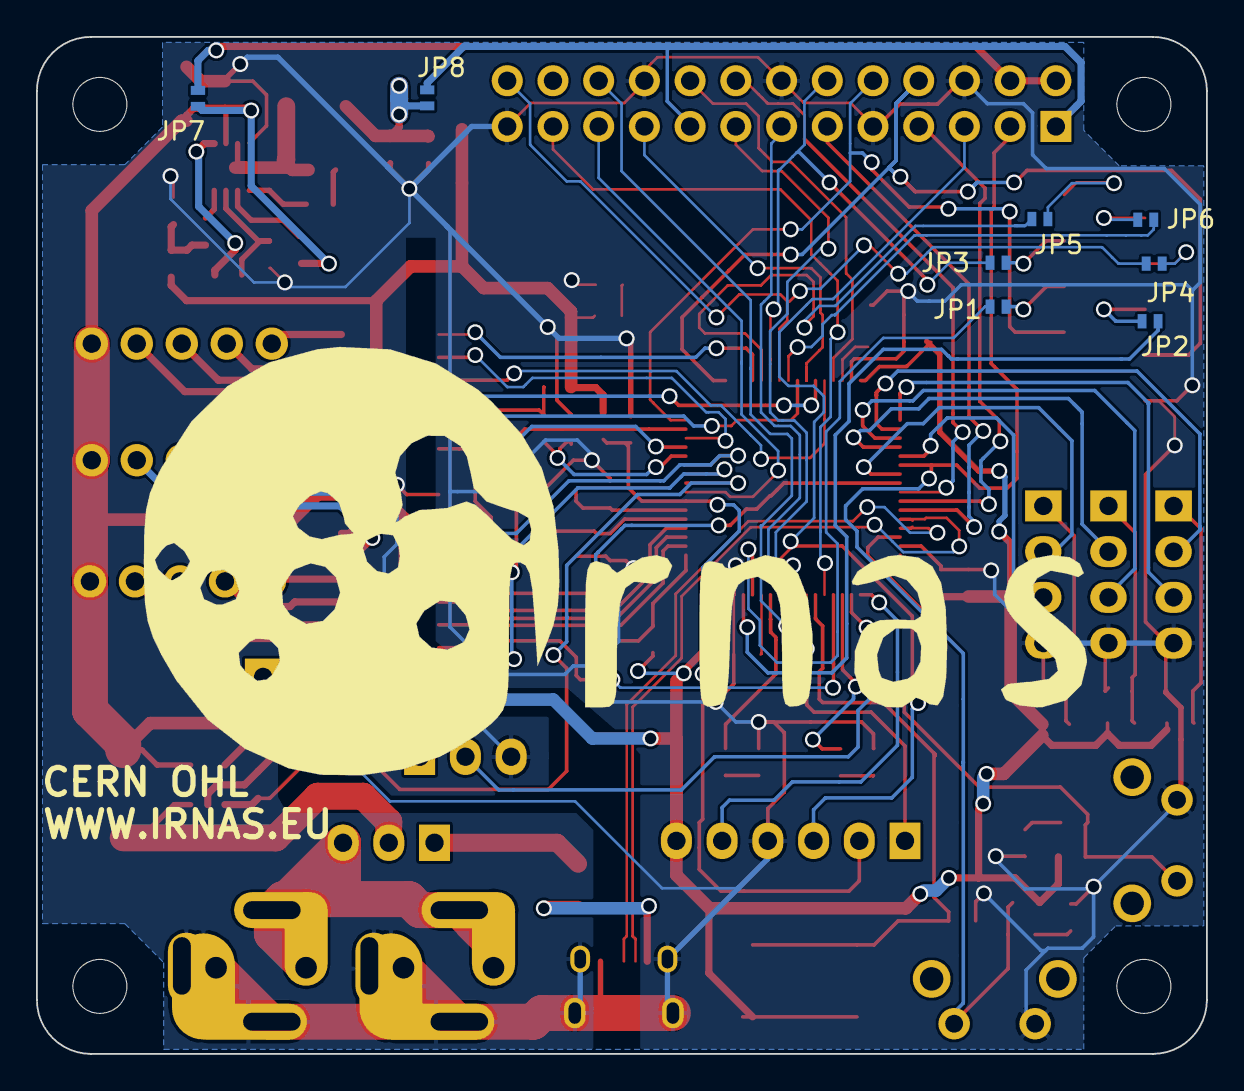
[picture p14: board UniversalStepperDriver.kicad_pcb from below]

Board: 2 copper layers, 65.0 x 56.5 mm, 83 parts (8 on the bottom side), 101 nets.

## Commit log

2016-04-18 all connected
    [UniversalStepperDriver.kicad_pcb, UniversalStepperDriver.sch]
2016-04-19 rev0.1 board done
    [UniversalStepperDriver.kicad_pcb, UniversalStepperDriver.sch]
2016-04-21 add gerber and BOM
    [StepperDriverBOM_farnell.csv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]
2016-07-18 P5 footprint fix
    [UniversalStepperDriver.kicad_pcb]
2016-07-18 P5 footprint Fixes #5
2016-07-18 PWR LED add Fixes #3
    [UniversalStepperDriver.kicad_pcb, UniversalStepperDriver.sch]
2016-07-18 add VCAP1 4.7u to PIN30(PB11) Fixes #2
    [UniversalStepperDriver.kicad_pcb, UniversalStepperDriver.sch]
2016-07-19 gerbers done for V3.1
    [UniversalStepperDriver-B.Cu.gbl, UniversalStepperDriver-B.Mask.gbs, UniversalStepperDriver-B.SilkS.gbo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]

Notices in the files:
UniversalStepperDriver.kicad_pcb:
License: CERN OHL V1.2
